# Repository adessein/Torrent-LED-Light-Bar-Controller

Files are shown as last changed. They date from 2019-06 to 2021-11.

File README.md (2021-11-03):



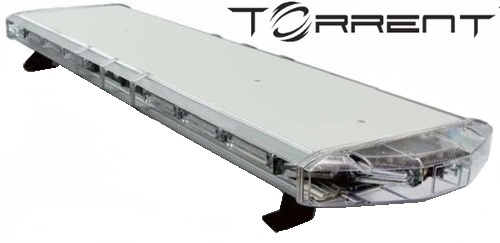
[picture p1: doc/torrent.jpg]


# Purpose
The purpose of this project is to create a Wifi controller for an orange Axixtech Torrent Led Light Bar.
This device is a safety light device that can be mounted on a vehicule for signaling danger, roadworks...
It is originaly delivered with a very simple control panel made of push buttons.

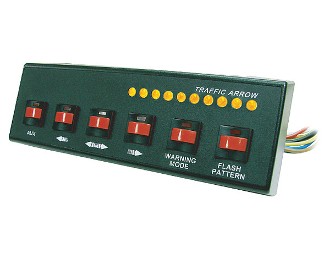
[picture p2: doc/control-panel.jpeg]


The purpose of this project is to create a system for the user to be able to control the light bar wirelessly, using his smartphone.

# Realisation

According to [the manual](../master/doc/TORRENT%20Lightbar%20Operation%20Manual.pdf) the bar is controlled by 15 wires. The voltage at these wires should either be 0 or 12V, respectively low and high level. Some wires should be hold at high level continuously of activating functions, more advanced ones requires mode selection by tapping several times on the wire (sending 12V pulses).

I have decided to make the electonic design as simple as possible: 
 - an ESP8266 is the main controllers: it creates a Wifi access point and sends a webpage to the client.
 - when the user select a function, the controller prepare the wire configuration state and pushes these states to shift registers.
 - since the voltae should be 12V, two Darlington NPN transistor arrays are used. Because they are NPN, they will be used to pull down the voltage when their emitter-base votage is positive. Which means that the controller should control using inversed logic (the shift registed should output 0V for the corresponding wire to be set to 12V and 3.3V for the wire to be set to 0V)

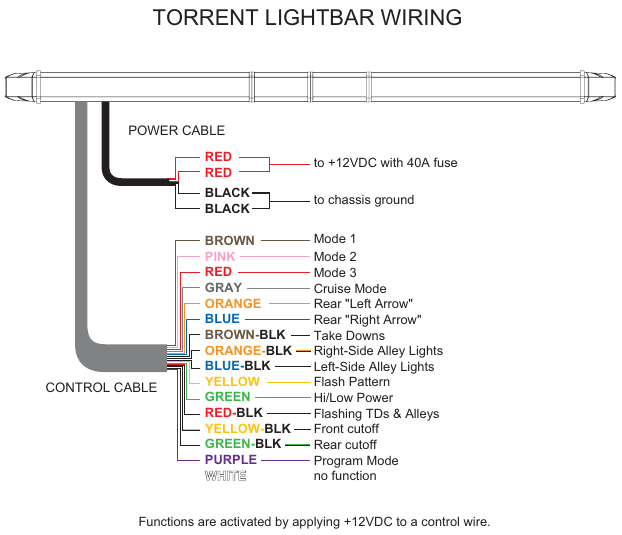
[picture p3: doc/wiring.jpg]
.

The ESP8266 micro-controller creates a Wifi access point.  
When connected to it, the user is redirected to a web page where he can change the illumination mode.  

  

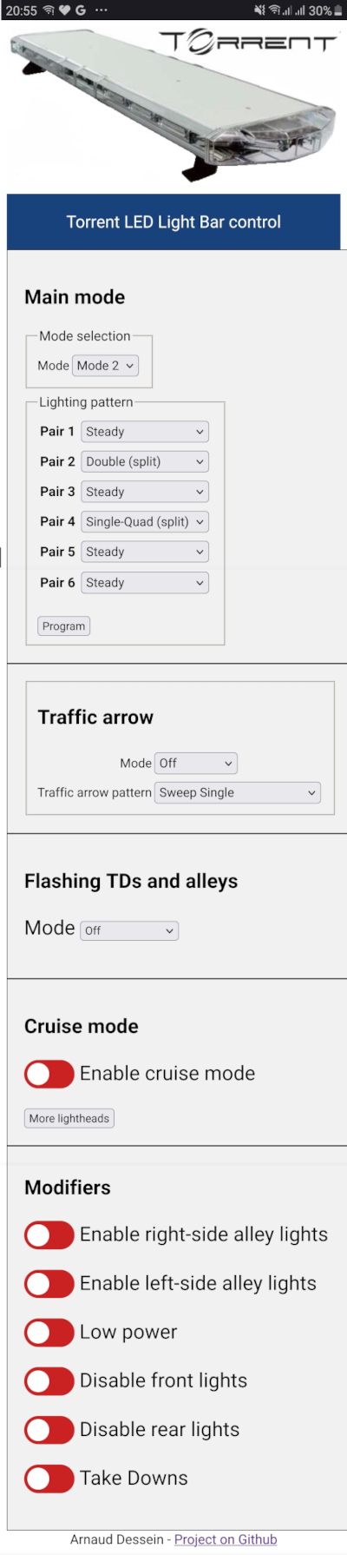
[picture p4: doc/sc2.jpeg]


## Code

The ESP8266 code contains the HTML page, therefore all the code is in one file [TorrentBar.ino](../master/TorrentBar/TorrentBar.ino).  
The webpage is also available in the file [TorrentBar.html](../master/doc/TorrentBar.html) for testing purposes.  

## Electronics

The circuit is rather simple, based on Darlington NPN transistor arrays and shift registers.  
The car battery supplies the 12V, which is reduced to 5V using a LM7805 voltage regulator.  
The 3.3V is either supplied by a LD1117V33 regulator (optional) or by the regulator located on the ESP8266 D1 Mini board.  

[My EDA project can be found here](https://easyeda.com/arnaud.dessein/torrent-light-bar)  

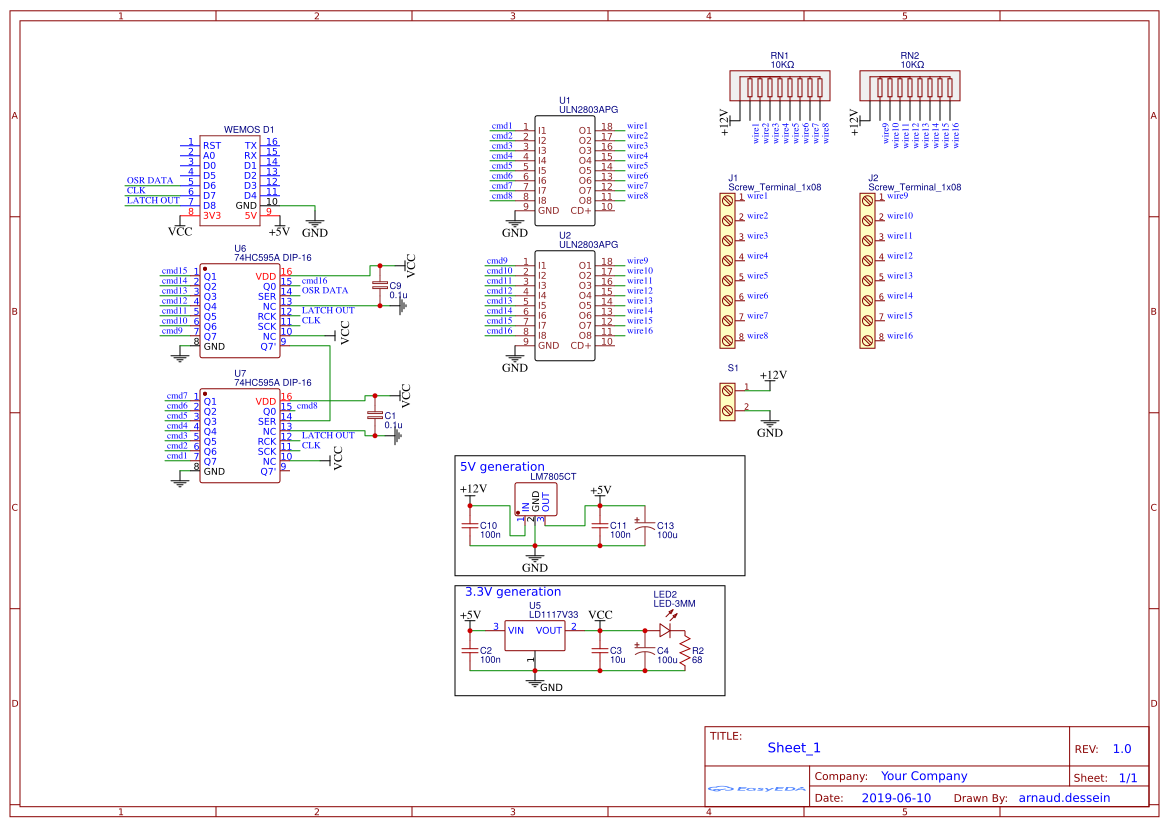
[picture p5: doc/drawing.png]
  

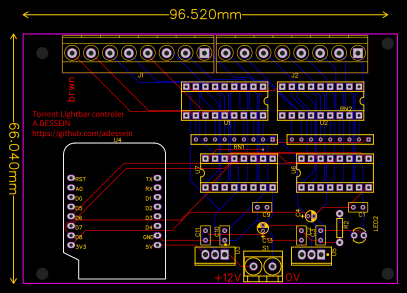
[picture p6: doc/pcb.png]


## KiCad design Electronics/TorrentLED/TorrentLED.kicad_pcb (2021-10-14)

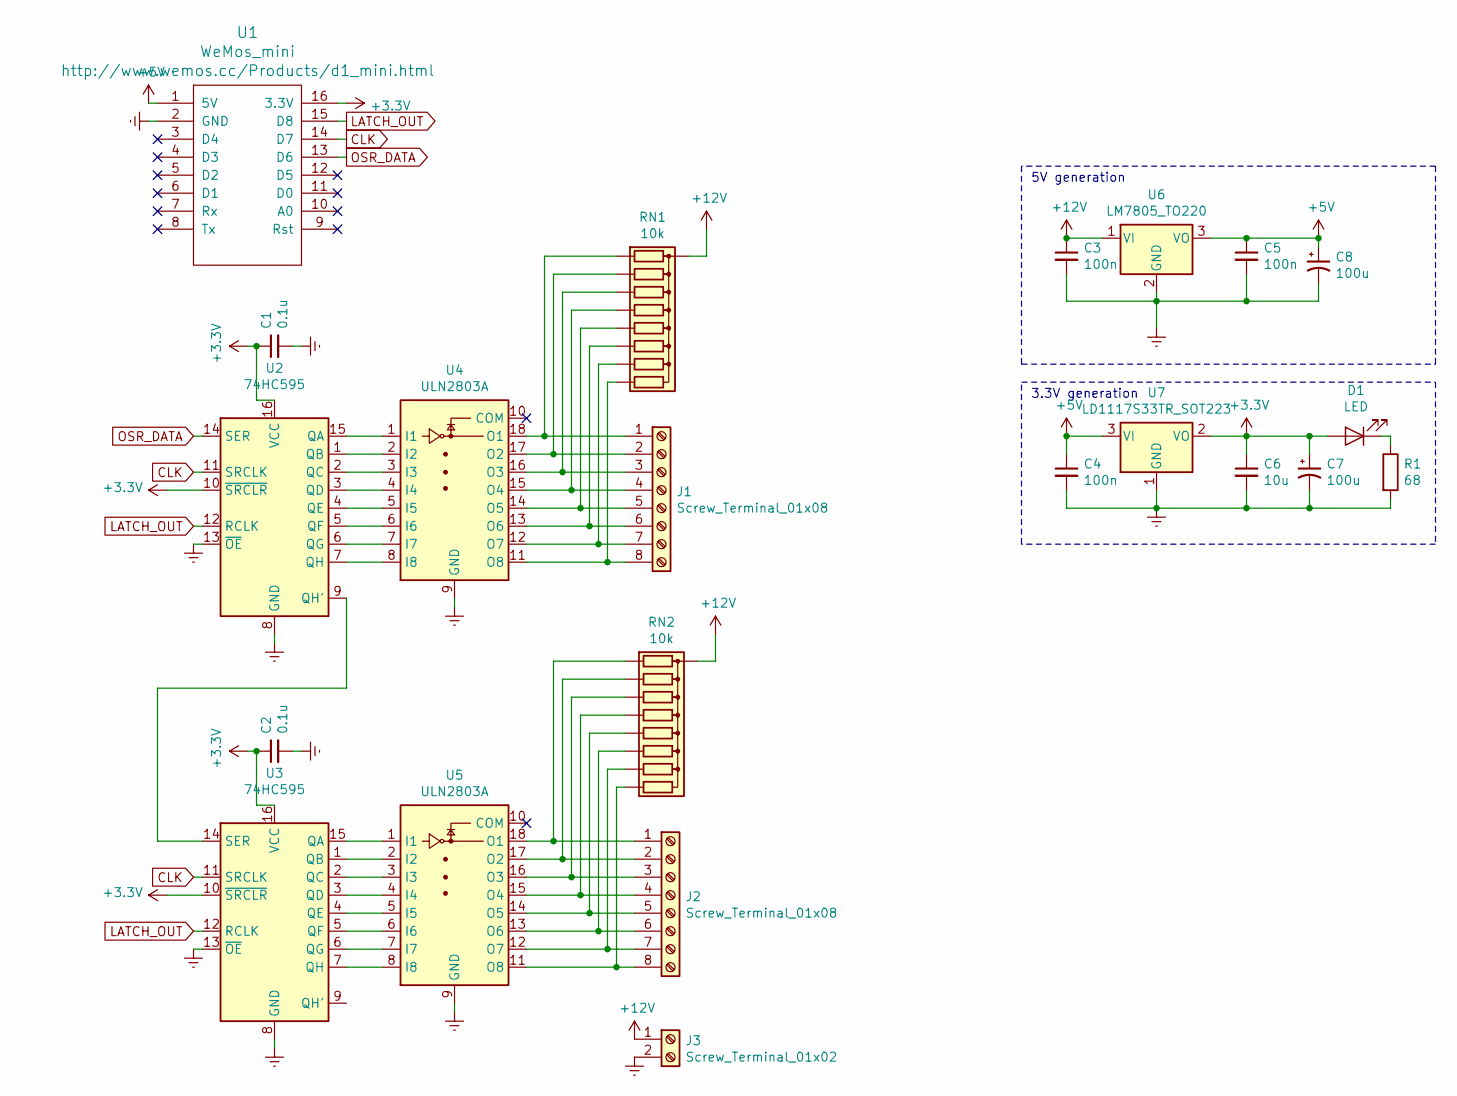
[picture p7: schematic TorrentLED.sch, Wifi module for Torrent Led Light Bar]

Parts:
C1, C2: 0.1u; C_Disc_D5.0mm_W2.5mm_P2.50mm
C3, C4, C5: 100n; C_Disc_D5.0mm_W2.5mm_P2.50mm
C6: 10u; C_Radial_D5.0mm_H11.0mm_P2.00mm
C7, C8: 100u; C_Radial_D6.3mm_H11.0mm_P2.50mm
D1: LED; LED_D3.0mm
J1, J2: Screw_Terminal_01x08; TerminalBlock_Phoenix_PT-1,5-8-5.0-H_1x08_P5.00mm_Horizontal
J3: Screw_Terminal_01x02; TerminalBlock_Phoenix_PT-1,5-2-5.0-H_1x02_P5.00mm_Horizontal
R1: 68; R_Axial_DIN0204_L3.6mm_D1.6mm_P7.62mm_Horizontal
RN1, RN2: 10k; R_Array_SIP9
U1: WeMos_mini; D1_mini_board
U2, U3: 74HC595; DIP-16_W7.62mm_Socket
U4, U5: ULN2803A; DIP-18_W7.62mm_Socket
U6: LM7805_TO220; TO-220-3_Vertical
U7: LD1117S33TR_SOT223; TO-220-3_Vertical

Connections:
+3V3: C1.1, C2.1, C6.1, C7.1, D1.2 (A), U1.16 (3.3V), U2.10 (~SRCLR), U2.16 (VCC), U3.10 (~SRCLR), U3.16 (VCC), U7.2 (VO)
+5V: C4.1, C5.1, C8.1, U1.1 (5V), U6.3 (VO), U7.3 (VI)
+12V: C3.1, J3.1, RN1.1 (common), RN2.1 (common), U6.1 (VI)
CLK: U1.14 (D7), U2.11 (SRCLK), U3.11 (SRCLK)
Earth: C1.2, C2.2, C3.2, C4.2, C5.2, C6.2, C7.2, C8.2, J3.2, R1.2, U1.2 (GND), U2.8 (GND), U2.13 (~OE), U3.8 (GND), U3.13 (~OE), U4.9 (GND), U5.9 (GND), U6.2 (GND), U7.1 (GND)
LATCH_OUT: U1.15 (D8), U2.12 (RCLK), U3.12 (RCLK)
unnamed: D1.1 (K), R1.1
unnamed: J1.1, RN1.2 (R1), U4.18 (O1)
unnamed: J1.2, RN1.3 (R2), U4.17 (O2)
unnamed: J1.3, RN1.4 (R3), U4.16 (O3)
unnamed: J1.4, RN1.5 (R4), U4.15 (O4)
unnamed: J1.5, RN1.6 (R5), U4.14 (O5)
unnamed: J1.6, RN1.7 (R6), U4.13 (O6)
unnamed: J1.7, RN1.8 (R7), U4.12 (O7)
unnamed: J1.8, RN1.9 (R8), U4.11 (O8)
unnamed: J2.1, RN2.2 (R1), U5.18 (O1)
unnamed: J2.2, RN2.3 (R2), U5.17 (O2)
unnamed: J2.3, RN2.4 (R3), U5.16 (O3)
unnamed: J2.4, RN2.5 (R4), U5.15 (O4)
unnamed: J2.5, RN2.6 (R5), U5.14 (O5)
unnamed: J2.6, RN2.7 (R6), U5.13 (O6)
unnamed: J2.7, RN2.8 (R7), U5.12 (O7)
unnamed: J2.8, RN2.9 (R8), U5.11 (O8)
unnamed: U2.1 (QB), U4.2 (I2)
unnamed: U2.2 (QC), U4.3 (I3)
unnamed: U2.3 (QD), U4.4 (I4)
unnamed: U2.4 (QE), U4.5 (I5)
unnamed: U2.5 (QF), U4.6 (I6)
unnamed: U2.6 (QG), U4.7 (I7)
unnamed: U2.7 (QH), U4.8 (I8)
unnamed: U2.9 (QH'), U3.14 (SER)
unnamed: U2.15 (QA), U4.1 (I1)
unnamed: U3.1 (QB), U5.2 (I2)
unnamed: U3.2 (QC), U5.3 (I3)
unnamed: U3.3 (QD), U5.4 (I4)
unnamed: U3.4 (QE), U5.5 (I5)
unnamed: U3.5 (QF), U5.6 (I6)
unnamed: U3.6 (QG), U5.7 (I7)
unnamed: U3.7 (QH), U5.8 (I8)
unnamed: U3.15 (QA), U5.1 (I1)
OSR_DATA: U1.13 (D6), U2.14 (SER)

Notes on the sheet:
5V generation
3.3V generation

Board: 2 copper layers, 22 parts (0 on the bottom side), 41 nets, no tracks yet.

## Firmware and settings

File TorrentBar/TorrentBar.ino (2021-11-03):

/*  Torrent LED Light Bar Controller
 *  The purpose of this project is to create a Wifi controller for an orange Axixtech Torrent Led Light Bar.  
 *  https://github.com/adessein/Torrent-LED-Light-Bar-Controller/
 *  GNU GENERAL PUBLIC LICENSE v3
 *  Arnaud DESSEIN
 */
 
/*  # Documentation
 *
 *  ## Captive portal
 *  https://github.com/ojack/ESP8266-captive-portal-webserver/blob/master/captivePortalFileServer.ino
 *  https://gist.github.com/bbx10/5a2885a700f30af75fc5
 *  https://gist.github.com/bbx10/667e3d4f5f2c0831d00b
 * 
 *  ## Javascript
 * 
 * 
 *  ## Filesystem
 *  https://steve.fi/Hardware/d1-flash/
 *  If error while uploading, check that the serial terminal is closed
 *  
 *  # Requirements
 *  Arduino ESP8266 filesystem uploader
 *  https://github.com/esp8266/arduino-esp8266fs-plugin
 * 
 *  # Arduino JSON
 *  https://arduinojson.org/v6/assistant/
 *  
 */

/* Example of requests
GET http://192.168.1.1/status
POST http://192.168.1.1/update?takeDownLights=true
*/
 
#include <ESP8266WiFi.h>
#include <DNSServer.h>
#include <ESP8266WebServer.h>
#include <ESP8266mDNS.h>
#include <FS.h>
#include "ArduinoJson-v6.18.5.h"


// **** DECLARATIONS ****

// Server settings
const byte DNS_PORT = 53;
const char *ssid = "Torrent LED Bar";
IPAddress apIP(192, 168, 1, 1);
DNSServer dnsServer;
ESP8266WebServer webServer(80);

// I/O settings
const int dataPin = 12;   //Outputs the byte to transfer [D6]
const int loadPin = 15;   //Controls the internal transference of data in SN74HC595 internal registers (LATCH) [D8]
const int clockPin = 13; //Generates the clock signal to control the transference of data [D7]

// Shift registers status byte
byte datah = 0xFF;
byte datal = 0;

// JSON and file buffers
char JSONmessageBuffer[1000];
String configFileBuffer;
DynamicJsonDocument doc(1024);

// Machine states
bool crossPattern;
bool cruiseMode;
bool flashingTdsAlleys;
short lightheadPatterns[6]; // 0 to 19
short mode;
short flashPattern; // 0 to 20
short flashingTdsAlleysMode; // 0 to 3 (TD + Alley, Alley, TD)
short trafficArrowsMode; // 0 to 3 (left, right, center out)
short trafficArrowsPattern; // 0 to 10
// Machine states: modifiers
bool rightSideAlley;
bool leftSideAlley;
bool lowPower;
bool frontCutoff;
bool rearCutoff;
bool takeDownLights;
// Internal representation of the output
bool W[16]; // state of the wires

// Function pototypes
void tapWire(int, int, bool);
void setup();
void loop();
void sendCSS();
void sendjQuery();
void sendConfig();
void writeRegister(byte, byte);
void dumpArgs();
void sendIndex();
void status();
void update();
void updateConfigWithSSPIFS();

// **** END DECLARATIONS ****

void setup(){
  Serial.begin(115200);
  
  Serial.println("=== Torrent LED Bar ===");
  Serial.println("Initialisation...");
  
  // Initialisation of the state
  for(int i=0;i<16;i++) W[i] = false;
  for(int i=0;i<6;i++) lightheadPatterns[i] = 0;
  mode = 1;
  crossPattern = false;
  flashPattern = 0;
  flashingTdsAlleys = false;
  flashingTdsAlleysMode = 0;
  cruiseMode = false;
  trafficArrowsMode = 0;
  trafficArrowsMode = 0;
  trafficArrowsPattern = 0;
  // mods
  rightSideAlley = false;
  leftSideAlley = false;
  lowPower = false;
  frontCutoff = false;
  rearCutoff = false;
  takeDownLights = false;

  Serial.print("  Configuring I/Os...");
  pinMode(dataPin, OUTPUT);
  pinMode(loadPin, OUTPUT);
  pinMode(clockPin, OUTPUT);
  Serial.println(" OK !");

  SPIFFS.begin();
  updateConfigWithSPIFFS();

  Serial.print("  Configuring Wifi...");
  WiFi.mode(WIFI_AP);
  WiFi.softAPConfig(apIP, apIP, IPAddress(255, 255, 255, 0));
  WiFi.softAP(ssid);
  Serial.println(" OK !");

  Serial.print("  Configuring DNS...");
  // if DNSServer is started with "*" for domain name, it will reply with
  // provided IP to all DNS request  
  dnsServer.start(DNS_PORT, "*", apIP);
  Serial.println("OK !");

  Serial.print("  Starting web server... ");
  webServer.on("/", sendIndex);
  webServer.on("/jquery.min.js", sendjQuery);
  webServer.on("/styles.css", sendCSS);
  webServer.on("/config.json", sendConfig);
  webServer.on("/wait.gif", sendWait);
  webServer.on("/torrent.jpg", sendTorrentJpg);
  webServer.on("/update", HTTP_POST, receiveJsonFromClient);
  webServer.on("/status", HTTP_GET, status);
  webServer.begin();
  Serial.println("OK !");
}

void updateConfigWithSPIFFS()
{
  Serial.print("  Reading settings file from EEPROM... ");
  // Load previous configuration from file in EPROM if exists
  File configFile = SPIFFS.open("/config.json", "r");
  // We need to put the content of the file in a String for deserealisation
  while (configFile.available()) configFileBuffer += char(configFile.read());
  configFile.close();

  Serial.println("OK !");
  Serial.print("  Content of the JSON file: ");
  Serial.println(configFileBuffer);

  if(configFileBuffer.length()>0)
  {
    Serial.print("  Deserializing configuration from EPROM...");
    StaticJsonDocument<500> configuration;
    deserializeJson(configuration, configFileBuffer);
    Serial.println(" OK !");
    update(configuration);
  }
  else
  {
    Serial.println("No configuration in EPROM... ");
  }
}

void loop()
{
  dnsServer.processNextRequest();
  webServer.handleClient();
}

void sendjQuery()
{
  // Sends the file jquery.min.j to the client on request (uploaded with the binary)
  Serial.print("Sending jQuery...");
  File f = SPIFFS.open("/jquery.min.js", "r");
  webServer.streamFile(f, "application/javascript");
  f.close();
  Serial.println(" OK !");
}

void sendTorrentJpg()
{
  // Sends the file torrent.jpg to the client on request (uploaded with the binary)
  Serial.print("Sending torrent.jpg...");
  File f = SPIFFS.open("/torrent.jpg", "r");
  webServer.streamFile(f, "jpeg");
  f.close();
  Serial.println(" OK !");
}

void sendCSS()
{
  // Sends the file styles.css to the client on request
  Serial.print("Sending CSS...");
  File f = SPIFFS.open("/styles.css", "r");
  webServer.streamFile(f, "text/css");
  f.close();
  Serial.println(" OK !");
}

void sendConfig()
{
  // This is jsut for debug
  Serial.print("Sending config.json...");
  File f = SPIFFS.open("/config.json", "r");
  webServer.streamFile(f, "text/json");
  f.close();
  Serial.println(" OK !");
}

void sendWait()
{
  Serial.print("Sending wait.gif... ");
  File f = SPIFFS.open("/wait.gif", "r");
  webServer.streamFile(f, "image/gif");
  f.close();
  Serial.println(" OK !");
}

void writeRegister(byte bh, byte bl)
{
  //Serial.print(bh, BIN); Serial.print(" "); Serial.println(bl, BIN); 
  Serial.print(datah, BIN);
  Serial.print("-");
  Serial.println(datal, BIN);

  digitalWrite(loadPin, LOW);
  shiftOut(dataPin, clockPin, MSBFIRST, bl);
  shiftOut(dataPin, clockPin, MSBFIRST, bh);
  digitalWrite(loadPin, HIGH);
}

void sendIndex()
{
  Serial.print("Sending index page...");
  File f = SPIFFS.open("/TorrentBar.html", "r");
  webServer.streamFile(f, "text/html");
  f.close();
  Serial.println(" OK!");
}

void status()
{
  Serial.println("The client requested server's status:");
  Serial.print("  Preparing JSON file... ");
  // Returns the current state as JSON
  doc["mode"] = mode;

  doc["flashPattern"] = flashPattern; // Mode1 0 to 19
  doc["flashingTdsAlleysMode"] = flashingTdsAlleysMode; // 0 to 3 (TD + Alley, Alley, TD)
  doc["cruiseMode"] = cruiseMode;
  doc["trafficArrowsMode"] = trafficArrowsMode;
  doc["trafficArrowsPattern"] = trafficArrowsPattern;
  // mods
  doc["rightSideAlley"] = rightSideAlley;
  doc["leftSideAlley"] = leftSideAlley;
  doc["lowPower"] = lowPower;
  doc["frontCutoff"] = frontCutoff;
  doc["rearCutoff"] = rearCutoff;
  doc["takeDownLights"] = takeDownLights;
  doc["crossPattern"] = crossPattern;

  // Light patterns (mode 2)
  JsonArray data = doc.createNestedArray("lightheadPatterns");
  for(int i=0;i<6;i++) data.add(lightheadPatterns[i]);
  
  serializeJson(doc, JSONmessageBuffer, sizeof(JSONmessageBuffer));
  Serial.println("OK !");

  Serial.print("  Saving file in EEPROM... ");
  File file = SPIFFS.open("/config.json", "w");
  int bytesWritten = file.print(JSONmessageBuffer);
  if (bytesWritten > 0) {
      Serial.print(bytesWritten);
      Serial.println(" bytes written: OK !");
  } else {
      Serial.println("File write failed !");
  }
  file.close();

  Serial.print("  Replying to the client with the JSON file...");
  webServer.send(200, "text/json", JSONmessageBuffer);
  Serial.println(" OK !");
  // Serial.print("  Content of the JSON file: ");
  // Serial.println(JSONmessageBuffer);
}

void receiveJsonFromClient()
{
  Serial.print("Receiving commands from client...");
  StaticJsonDocument<500> payload;
  
  Serial.print("Payload received: ");
  Serial.println(webServer.arg("plain"));
  
  deserializeJson(payload, webServer.arg("plain"));
  Serial.println(" OK!");
  update(payload);
}

void update(StaticJsonDocument<500> payload)
{
  Serial.println("Updating configuration...");

  if (payload.containsKey("mode"))
  {
    // {mode: int (1 to 3)}
    mode = payload["mode"].as<int>();
    
    if(mode==1)
    {
      W[0] = true;
      W[1] = false;
      W[2] = false;
      W[3] = crossPattern; 
    }
    if(mode==2)
    {
      W[0] = false;
      W[1] = true;
      W[2] = false;
    }
    if(mode==3)
    {
      W[0] = false;
      W[1] = false;
      W[2] = true;
    }
  }

  if(payload.containsKey("cruiseMode")) cruiseMode = payload["cruiseMode"]; // green-black

  if(payload.containsKey("cruiseMoreLightheads"))
  {
    // Tap purple W[14] a single time
    tapWire(14, 1, false);
  }

  if(payload.containsKey("flashPattern"))
  {
    flashPattern = payload["flashPattern"].as<int>();

    // Tap 3 times in a second W[9] to reset
    tapWire(9, 3, true);
    // Tap flashPattern times W[9]
    tapWire(9, flashPattern, false);
  }

  if(payload.containsKey("lightheadPatterns"))
  {
    for(int i=0;i<6;i++)
    {
      lightheadPatterns[i] = payload["lightheadPatterns"][i].as<int>();
    }

    // Tap 3 times in a second W[14] to enter program mode
    tapWire(14, 3, true);
    
    // For each pair
    for(int i=0; i<6; i++)
    {
      // Tap 3 times in a second W[9] to reset
      tapWire(9, 3, true);
      // Tap lightheadPatterns[i] times W[9]
      tapWire(9, lightheadPatterns[i], false);
      // Tap W[14] to move to next pair
      tapWire(14, 1, false);
    }

    // Tap 3 times in a second W[14] to exit program mode
    tapWire(14, 3, true);
  }

  if (payload.containsKey("trafficArrowsPattern"))
  {
    trafficArrowsPattern = payload["trafficArrowsPattern"].as<int>();

    // Tap 3 times in a second W[9] to reset 
    tapWire(9, 3, true);
    // Tap trafficArrowsPattern times W[9]
    tapWire(9, trafficArrowsPattern, false);
  }

  if(payload.containsKey("flashingTdsAlleysMode"))
  {
    flashingTdsAlleysMode = payload["flashingTdsAlleysMode"].as<int>();
    
    flashingTdsAlleys = flashingTdsAlleysMode == 0 ? false:true;

    if(flashingTdsAlleysMode>0)
    {
      // I need to activate the wire now, since I need to configure
      setWire(11, true); // Red-black

      // Tap flashingTdsAlleysMode times W[9]
      tapWire(9, flashingTdsAlleysMode, false);
    }

  }

  if (payload.containsKey("trafficArrowsMode"))
  {
    trafficArrowsMode = payload["trafficArrowsMode"].as<int>();
    W[4] = trafficArrowsMode == 1 || trafficArrowsMode == 3 ? 1:0; // orange
    W[5] = trafficArrowsMode == 2 || trafficArrowsMode == 3 ? 1:0; // blue
  }

  if (payload.containsKey("mod"))
  {
    if(payload["mod"] == "takeDownLights")    takeDownLights = payload["value"]; // brown-black
    if(payload["mod"] == "rightSideAlley")    rightSideAlley  = payload["value"]; // orange-black
    if(payload["mod"] == "leftSideAlley")     leftSideAlley = payload["value"]; // blue-black
    if(payload["mod"] == "lowPower")          lowPower = payload["value"];  // green 
    if(payload["mod"] == "frontCutoff")       frontCutoff = payload["value"]; // yellow-black
    if(payload["mod"] == "rearCutoff")        rearCutoff = payload["value"]; // green-black  
    
    if(payload["mod"] == "crossPattern")    crossPattern = payload["value"];  
    if(payload["mod"] == "cruiseMode")      cruiseMode = payload["value"];  
  }

  W[3] = cruiseMode | crossPattern; // gray cruise mode or cross pattern
  W[6] = takeDownLights; // brown-black
  W[7] = rightSideAlley; // orange-black
  W[8] = leftSideAlley; // blue-black
  W[9] = 0; //yellow is tapped
  W[10] = lowPower;  // green
  W[11] = flashingTdsAlleys; // red-black
  W[12] = frontCutoff; // yellow-black
  W[13] = rearCutoff; // green-black
  W[14] = 0; //purple is tapped

  setWires();
  delay(100);
  status();
}

void setWires()
{
  Serial.print("  Preparing the signals to be sent to the bar...");
  // Reset the bytes
  datal = (byte)0xFF;
  datah = (byte)0xFF;

  Serial.print("W= ");
  for (int i=15;i>=0;i--) Serial.print(W[i]);
  Serial.println();

  for (int i=0;i<8;i++)  datal = datal & ~(W[i] << i); // Pull down
  for (int i=8;i<16;i++) datah = datah & ~(W[i] << i-8); // Pull down
  Serial.println(" OK !");

  Serial.print("Appling signals...");
  writeRegister(datah, datal);
  Serial.println(" OK !");
  
}

void setWire(int w, bool state)
{
  // Modifies the bytes to be sent to the shift registers
  // so that the wire *w* takes state *state*
  // state=true : Apply +12V
  // state=false : Apply 0V
  
  if(state==false) // I want to pull up
  {
    if(w<8)
    {
      datal = datal | (1 << w); // Pull up
    }
    else
    {
      datah = datah | (1 << w-8); // Pull up
    }
  }
  else
  {
    if(w<8)
    {
      datal = datal & ~(1 << w); // Pull down
    }
    else
    {
      datah = datah & ~(1 << w-8); // Pull down
    }
  }
  writeRegister(datah, datal);
}

void tapWire(int w, int N=1, bool fast=false)
{
  // Sets the wire *w* to +12V during 100 ms, before settting back to 0V.
  // This acction is repeated *N* times.
  // If *fast* is set to True, 100 ms between each tap, otherwise 400 ms.

  Serial.print("  Tapping wire "); Serial.print(w, DEC);
  Serial.print(" ("); Serial.print(N, DEC);
  Serial.println(" times)");
  for(int i=0; i<N; i++)
  {
    setWire(w, true);
    delay(200);
    setWire(w, false);

    if(fast) // triple tap
    {
      delay(100);
    }
    else
    {
      delay(400); // 3 taps at 450ms is above 1 sec
    }
  }

}

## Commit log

2019-06-11 Started to work on the ESP8266 program and the web page controlling the led bar
2019-06-12 Changed the HTML code so the checkboxes will triger the form submit when they are clicked, whatever their state. Then I added tags {Cn} that are modified in the ESP8266 program by the actual state of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
2019-06-13 Major update. Added all functions. Added control of the shift registers. Corrected some labels in webpage. Added debug messages on serial. I still have a problem with the page reloading several time 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
    [TorrentBar.ino]
2019-06-14 Simplified the code. Added a hidden parameter to make the difference between user and browser requests. Updated README with the final PCB and SCH (I have ordered the PCBs).
2019-06-16 Important changes - all features, CSS, FS
    The webpage that I have done before was not adapted to the complex way of
    controlling the bar. Indeed, reading the manual thoroughly made me
    understand that some modes could be programmed and that some features
    (modifiers) where incompatible with certain modes.
    I have separated the webpage from the ino file (it was embended as a
    const char[] defore). Now the webpage is only in the .html file, also
    used for testing. Therefore, the risk of differences between these two
    files is removed.
    I have also separated the CSS part of the webpage and included jQuery
    file. Because the bar might be accessed form a device without connection
    to internet, I had to e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
    [TorrentBar.ino]
2019-06-26 (WIP) Use jQuery, POST requests and ajax
    Still under development and to be tested.
    I am following the idea that any change of any control should
    trigger a POST request. In order to avoid the refreshing and
    clearing of the form, I return false.
    Indeed, I have abandoned the idea that the server should send a
    new page at every request, reflecting the changes. I prefer to
    rely on CSS and javascript to manage the controls.
    I am not able to test if my POST requests are properly sent.
    I should also check that the ESP8266 interpret them properly.
    [TorrentBar.ino]
2021-10-14 Working on making PCB with KiCad
    [TorrentLED.dsn, TorrentLED.kicad_pcb, TorrentLED.sch]
2021-10-14 Fixing order of bytes and progtam
    [TorrentBar.ino]
2021-10-22 Switches toggle on server's response
2021-11-03 Bug fixes and debug with the bar
    [TorrentBar.ino]
